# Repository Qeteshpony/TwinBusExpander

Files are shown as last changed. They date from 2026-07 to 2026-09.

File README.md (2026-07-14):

# TwinBusExpander



3D Render

[Hardware Documentation](https://qeteshpony.github.io/TwinBusExpander)

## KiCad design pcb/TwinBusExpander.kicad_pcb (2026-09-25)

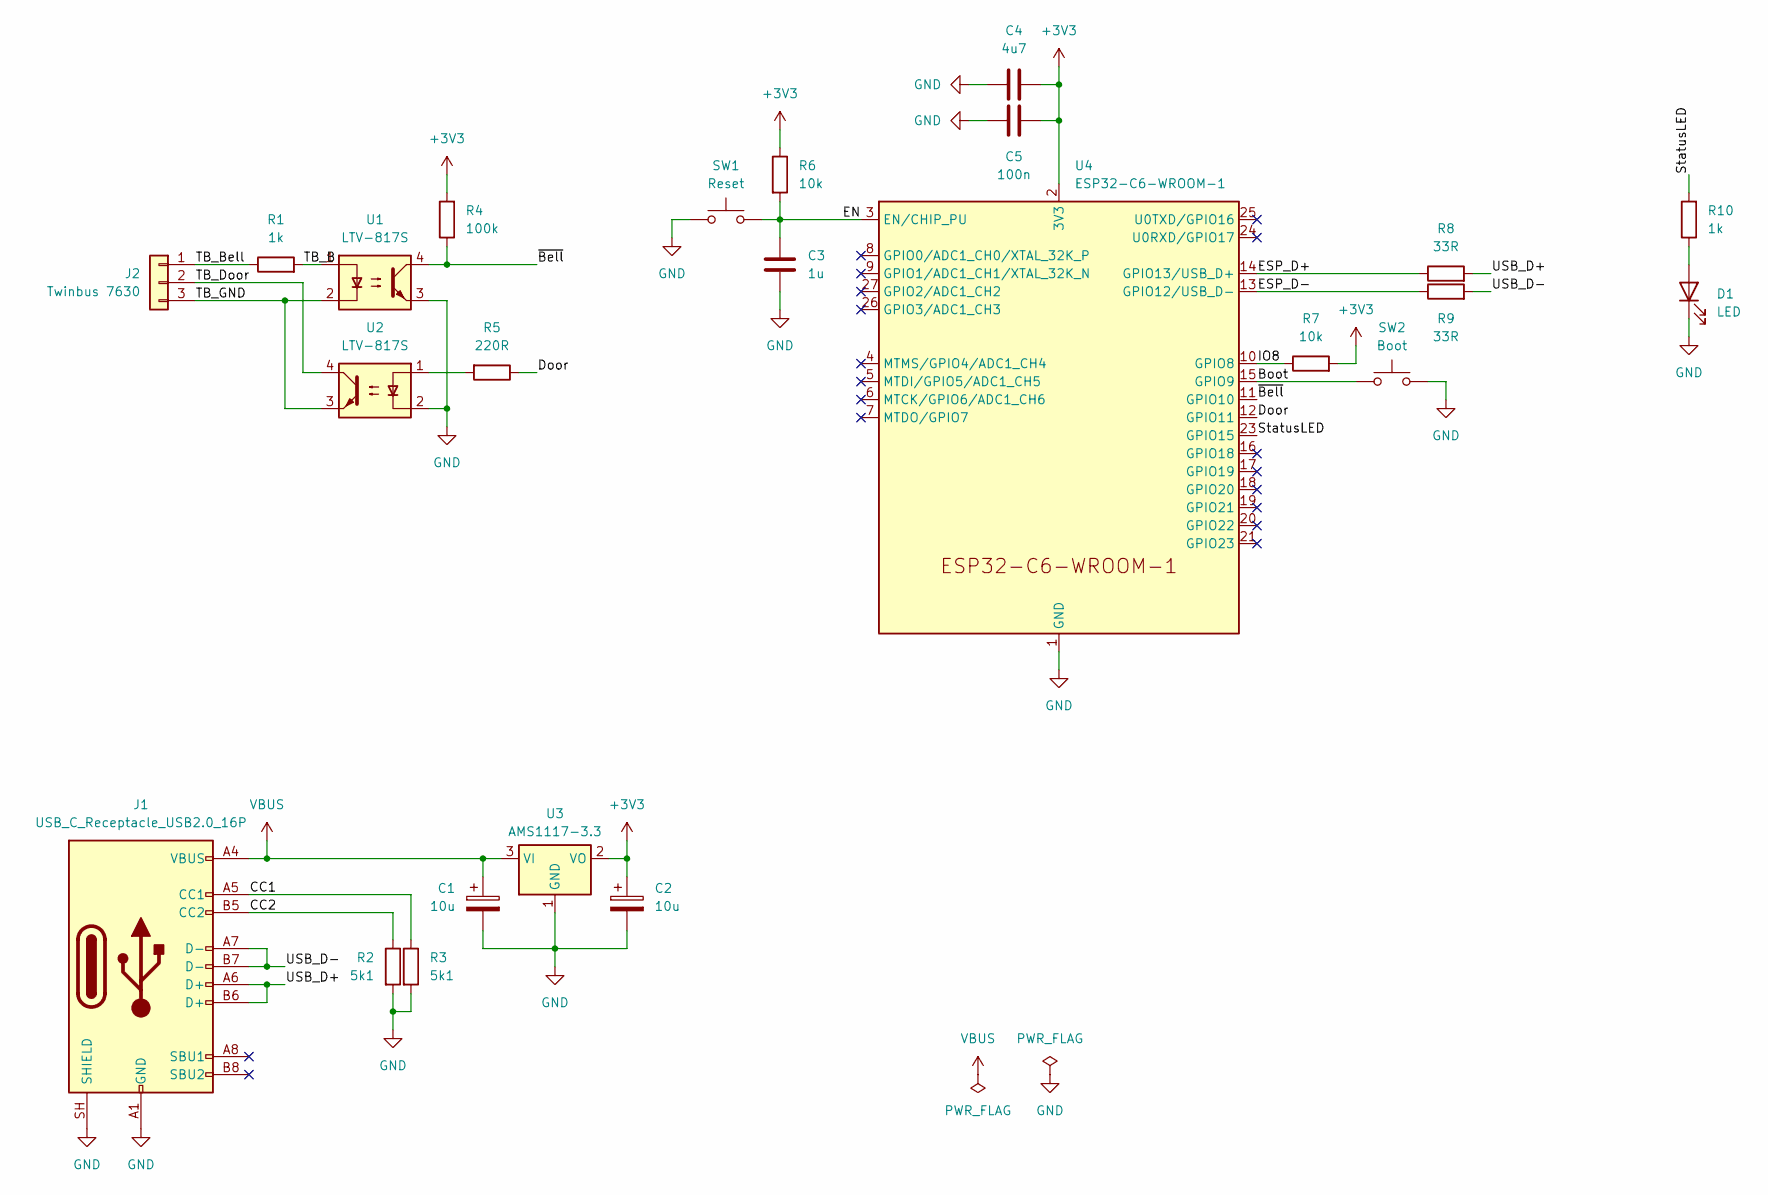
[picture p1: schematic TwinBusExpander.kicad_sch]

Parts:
C1, C2: 10u; CP_EIA-3216-18_Kemet-A; LCSC C7171
C3: 1u; C_0402_1005Metric; LCSC C52923
C4: 4u7; C_0402_1005Metric; LCSC C23733
C5: 100n; C_0402_1005Metric; LCSC C1525
D1: LED; LED_0603_1608Metric; LCSC C2286
J1: USB_C_Receptacle_USB2.0_16P; USB_C_Receptacle_GCT_USB4105-xx-A_16P_TopMnt_Horizontal; LCSC C393939
J2: Twinbus 7630; JST_PH_S3B-PH-K_1x03_P2.00mm_Horizontal; LCSC C157929
R1, R10: 1k; R_0402_1005Metric; LCSC C11702
R2, R3: 5k1; R_0402_1005Metric; LCSC C25905
R4: 100k; R_0402_1005Metric; LCSC C25741
R5: 220R; R_0402_1005Metric; LCSC C25091
R6, R7: 10k; R_0402_1005Metric; LCSC C25744
R8, R9: 33R; R_0402_1005Metric; LCSC C25105
SW1: Reset; SW_SPST_TS-1088-xR020; LCSC C720477
SW2: Boot; SW_SPST_TS-1088-xR020; LCSC C720477
U1, U2: LTV-817S; SMDIP-4_W9.53mm; LCSC C109227
U3: AMS1117-3.3; SOT-223-3_TabPin2; LCSC C6186
U4: ESP32-C6-WROOM-1

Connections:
+3V3: C2.1, C4.2, C5.2, R4.2, R6.1, R7.2, U3.2 (VO), U4.2 (3V3)
/Boot: SW2.1, U4.15 (GPIO9)
/CC1: J1.A5 (CC1), R3.1
/CC2: J1.B5 (CC2), R2.1
/Door: R5.1, U4.12 (GPIO11)
/EN: C3.1, R6.2, SW1.2, U4.3 (EN/CHIP_PU)
/ESP_D+: R8.1, U4.14 (GPIO13/USB_D+)
/ESP_D-: R9.1, U4.13 (GPIO12/USB_D-)
/IO8: R7.1, U4.10 (GPIO8)
/StatusLED: R10.2, U4.23 (GPIO15)
/TB_B: R1.2, U1.1
/TB_Bell: J2.1, R1.1
/TB_Door: J2.2, U2.4
/TB_GND: J2.3, U1.2, U2.3
/USB_D+: J1.A6 (D+), J1.B6 (D+), R8.2
/USB_D-: J1.A7 (D-), J1.B7 (D-), R9.2
/~Bell: R4.1, U1.4, U4.11 (GPIO10)
GND: C1.2, C2.2, C3.2, C4.1, C5.1, D1.1 (K), J1.A1 (GND), J1.A12 (GND), J1.B1 (GND), J1.B12 (GND), J1.SH (SHIELD), R2.2, R3.2, SW1.1, SW2.2, U1.3, U2.2, U3.1 (GND), U4.1 (GND), U4.28 (GND), U4.29 (GND)
unnamed: D1.2 (A), R10.1
unnamed: R5.2, U2.1
VBUS: C1.1, J1.A4 (VBUS), J1.A9 (VBUS), J1.B4 (VBUS), J1.B9 (VBUS), U3.3 (VI)

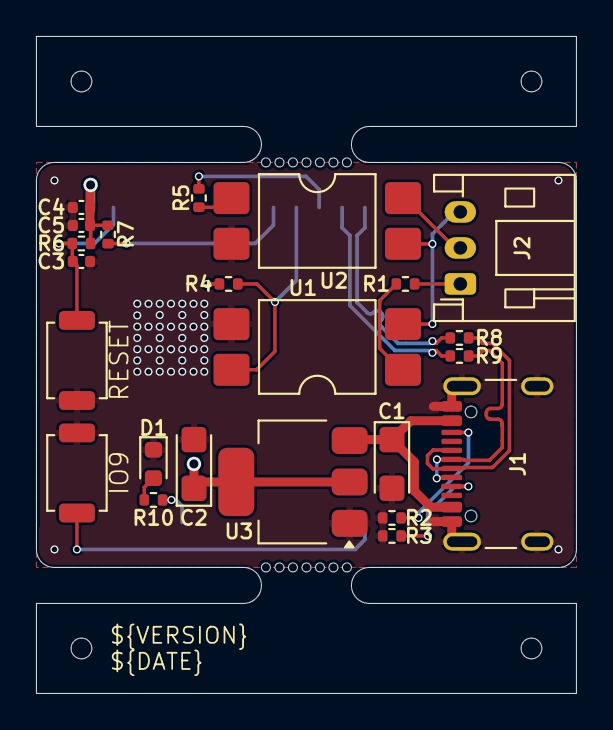
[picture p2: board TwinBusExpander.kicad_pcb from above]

Board: 4 copper layers, 30.0 x 36.5 mm, 26 parts (1 on the bottom side), 21 nets.

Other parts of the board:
mouse-bite-2mm-slot, mouse-bite-2mm-slot#2: VAL**; mouse-bite-2x5mm-slot-onesided-v2

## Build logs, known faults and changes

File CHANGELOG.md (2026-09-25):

# Changelog

## [1.1.1](https://github.com/Qeteshpony/TwinBusExpander/compare/v1.1.0...v1.1.1) (2026-09-25)

### Bug Fixes

* minimum via size ([19418e9](https://github.com/Qeteshpony/TwinBusExpander/commit/19418e93414083f47cbac3ffd821efa599ae9465))

## [1.1.0](https://github.com/Qeteshpony/TwinBusExpander/compare/v1.0.0...v1.1.0) (2026-09-25)

### Features

* add edge rails ([663115f](https://github.com/Qeteshpony/TwinBusExpander/commit/663115f8c4a8d57f01fc17087f7954e541f37562))

## 1.0.0 (2026-09-25)

### ⚠ BREAKING CHANGES

* remove speaker completely

### Features

* initial commit ([d8b0a1a](https://github.com/Qeteshpony/TwinBusExpander/commit/d8b0a1a0def7a7ac8381d5536d8986a71eb250a7))
* remove speaker completely ([c9edf8f](https://github.com/Qeteshpony/TwinBusExpander/commit/c9edf8fed0e19e035d66f667929501e73f4a2c3b))
* replace Optoisolators ([1664309](https://github.com/Qeteshpony/TwinBusExpander/commit/16643092be0a931966f33e3db97c917e997d6c6f))

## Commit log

2026-07-14 feat: initial commit
    [TwinBusExpander.kicad_pcb, TwinBusExpander.kicad_sch]
2026-07-20 feat!: remove speaker completely
    Speaker didnt work as planned, removed. Board got a lot smaller.
    [TwinBusExpander.kicad_pcb, TwinBusExpander.kicad_sch]
2026-09-25 feat: replace Optoisolators
    Replace generic PC817 with LTV-817S because of part availability
    [TwinBusExpander.kicad_pcb, TwinBusExpander.kicad_sch]
2026-09-25 feat: add edge rails
    [TwinBusExpander.kicad_pcb]
2026-09-25 fix: minimum via size
    change vias from 0.2 to 0.3mm for cheaper production
    [TwinBusExpander.kicad_pcb]
